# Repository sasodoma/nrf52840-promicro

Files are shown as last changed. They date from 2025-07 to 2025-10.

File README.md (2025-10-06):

# nRF52840 ProMicro

The nRF52840 ProMicro board is also known as the SuperMini board. It's a clone of the nice!nano board with a mix of v1 and v2 design features. The schematic is available online, albeit with a small mistake, but I was unable to find board design files. The aim of this repository is to reverse engineer the board design and determine which component is which so that I can desolder them from the board and reuse them on my custom PCB.

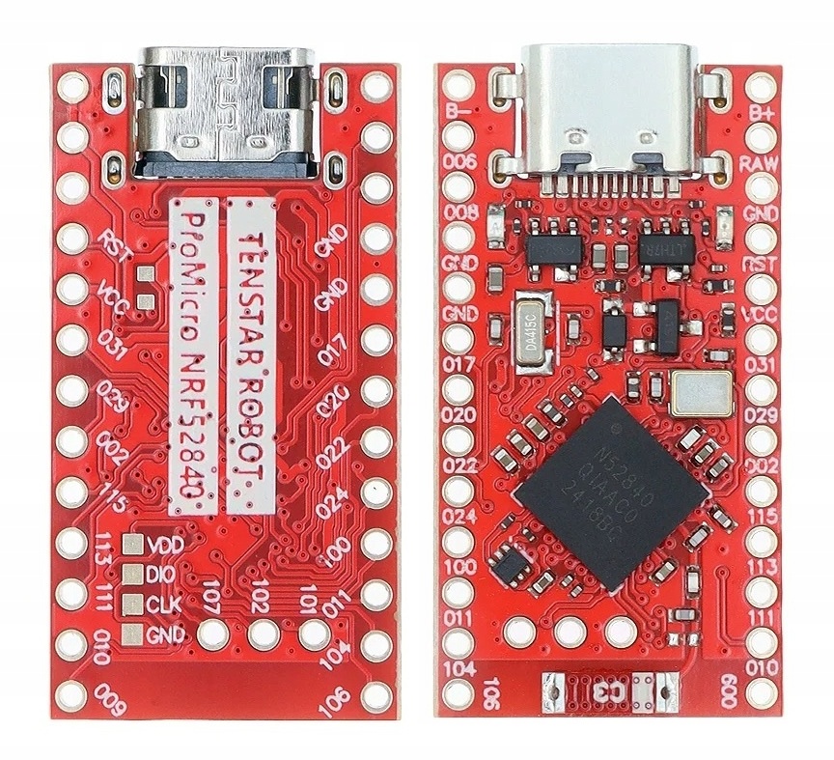
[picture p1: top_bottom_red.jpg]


# Schematic
This is the original schematic as posted on https://chat.nologo.tech/d/80. The voltage divider for the battery is marked as being connected to P0.04, which is an analog input pin. On the actual board it's connected to P0.24 instead, which makes it unsuitable for battery voltage measurements. Instead you can measure the battery directly on VDDH pin, but the voltage will rise when USB is plugged in. To prevent this incorrect reading, you can remove the NPQ2, NBD1 and NPR7 components, and instead bridge pins 3 and 2 on the NPQ2 MOSFET. This way the nRF chip will always draw power from the battery and USB will only charge the battery and thus power the board indirectly. The voltage on VDDH will then be the actual voltage of the battery (slightly higher while charging but it won't jump to 100%). This could be problematic if your board consumed more current than the charger provided, and the battery would discharge while plugged in, so keep that in mind.

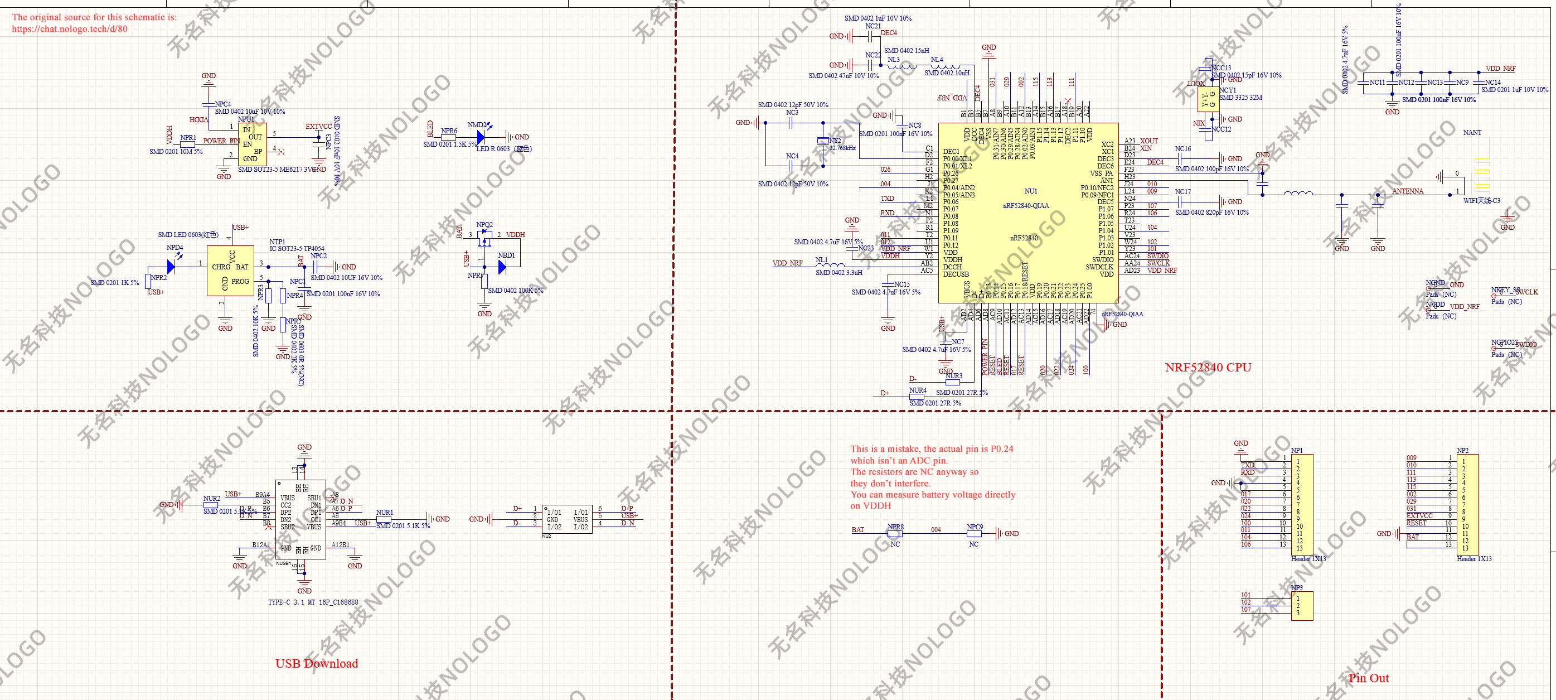
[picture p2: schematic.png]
Schematic of the nRF52840 ProMicro board


# Sleep current problems
I wanted to use these boards to create some low power BTHome sensors. I have boards from many different sources. Some exhibit great power consumption, only 4 uA in sleep, with EXTVCC disabled. Others had a consumption of 60 uA, which is still pretty good but it's 15x more. After some component swapping, I found the problem to be the W5 marked diode. This is supposed to be a BAT60B Schottky diode, with a voltage drop of 0.24 V. On the high power consumption boards I instead measured a drop of 0.7 V, indicating a regular silicon diode. What's more concerning is that apparently the reverse leakage current of this diode was also much worse and this is what was causing the power consumption.

# KiCad project
The project in the KiCad folder is my attempt at replicating the board to identify every component's location. The USB connector is not the correct footprint, but the name in the schematic is correct. KiCad doesn't seem to have a footprint for the antenna, but the model is CA-C03.

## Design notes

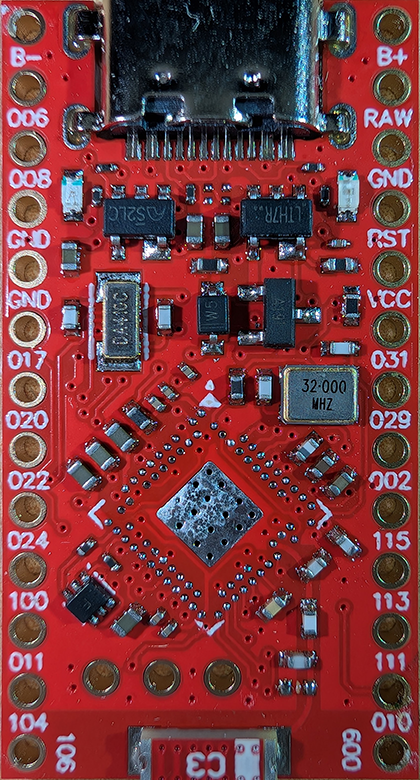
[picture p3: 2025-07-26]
KiCad/reference_top.png

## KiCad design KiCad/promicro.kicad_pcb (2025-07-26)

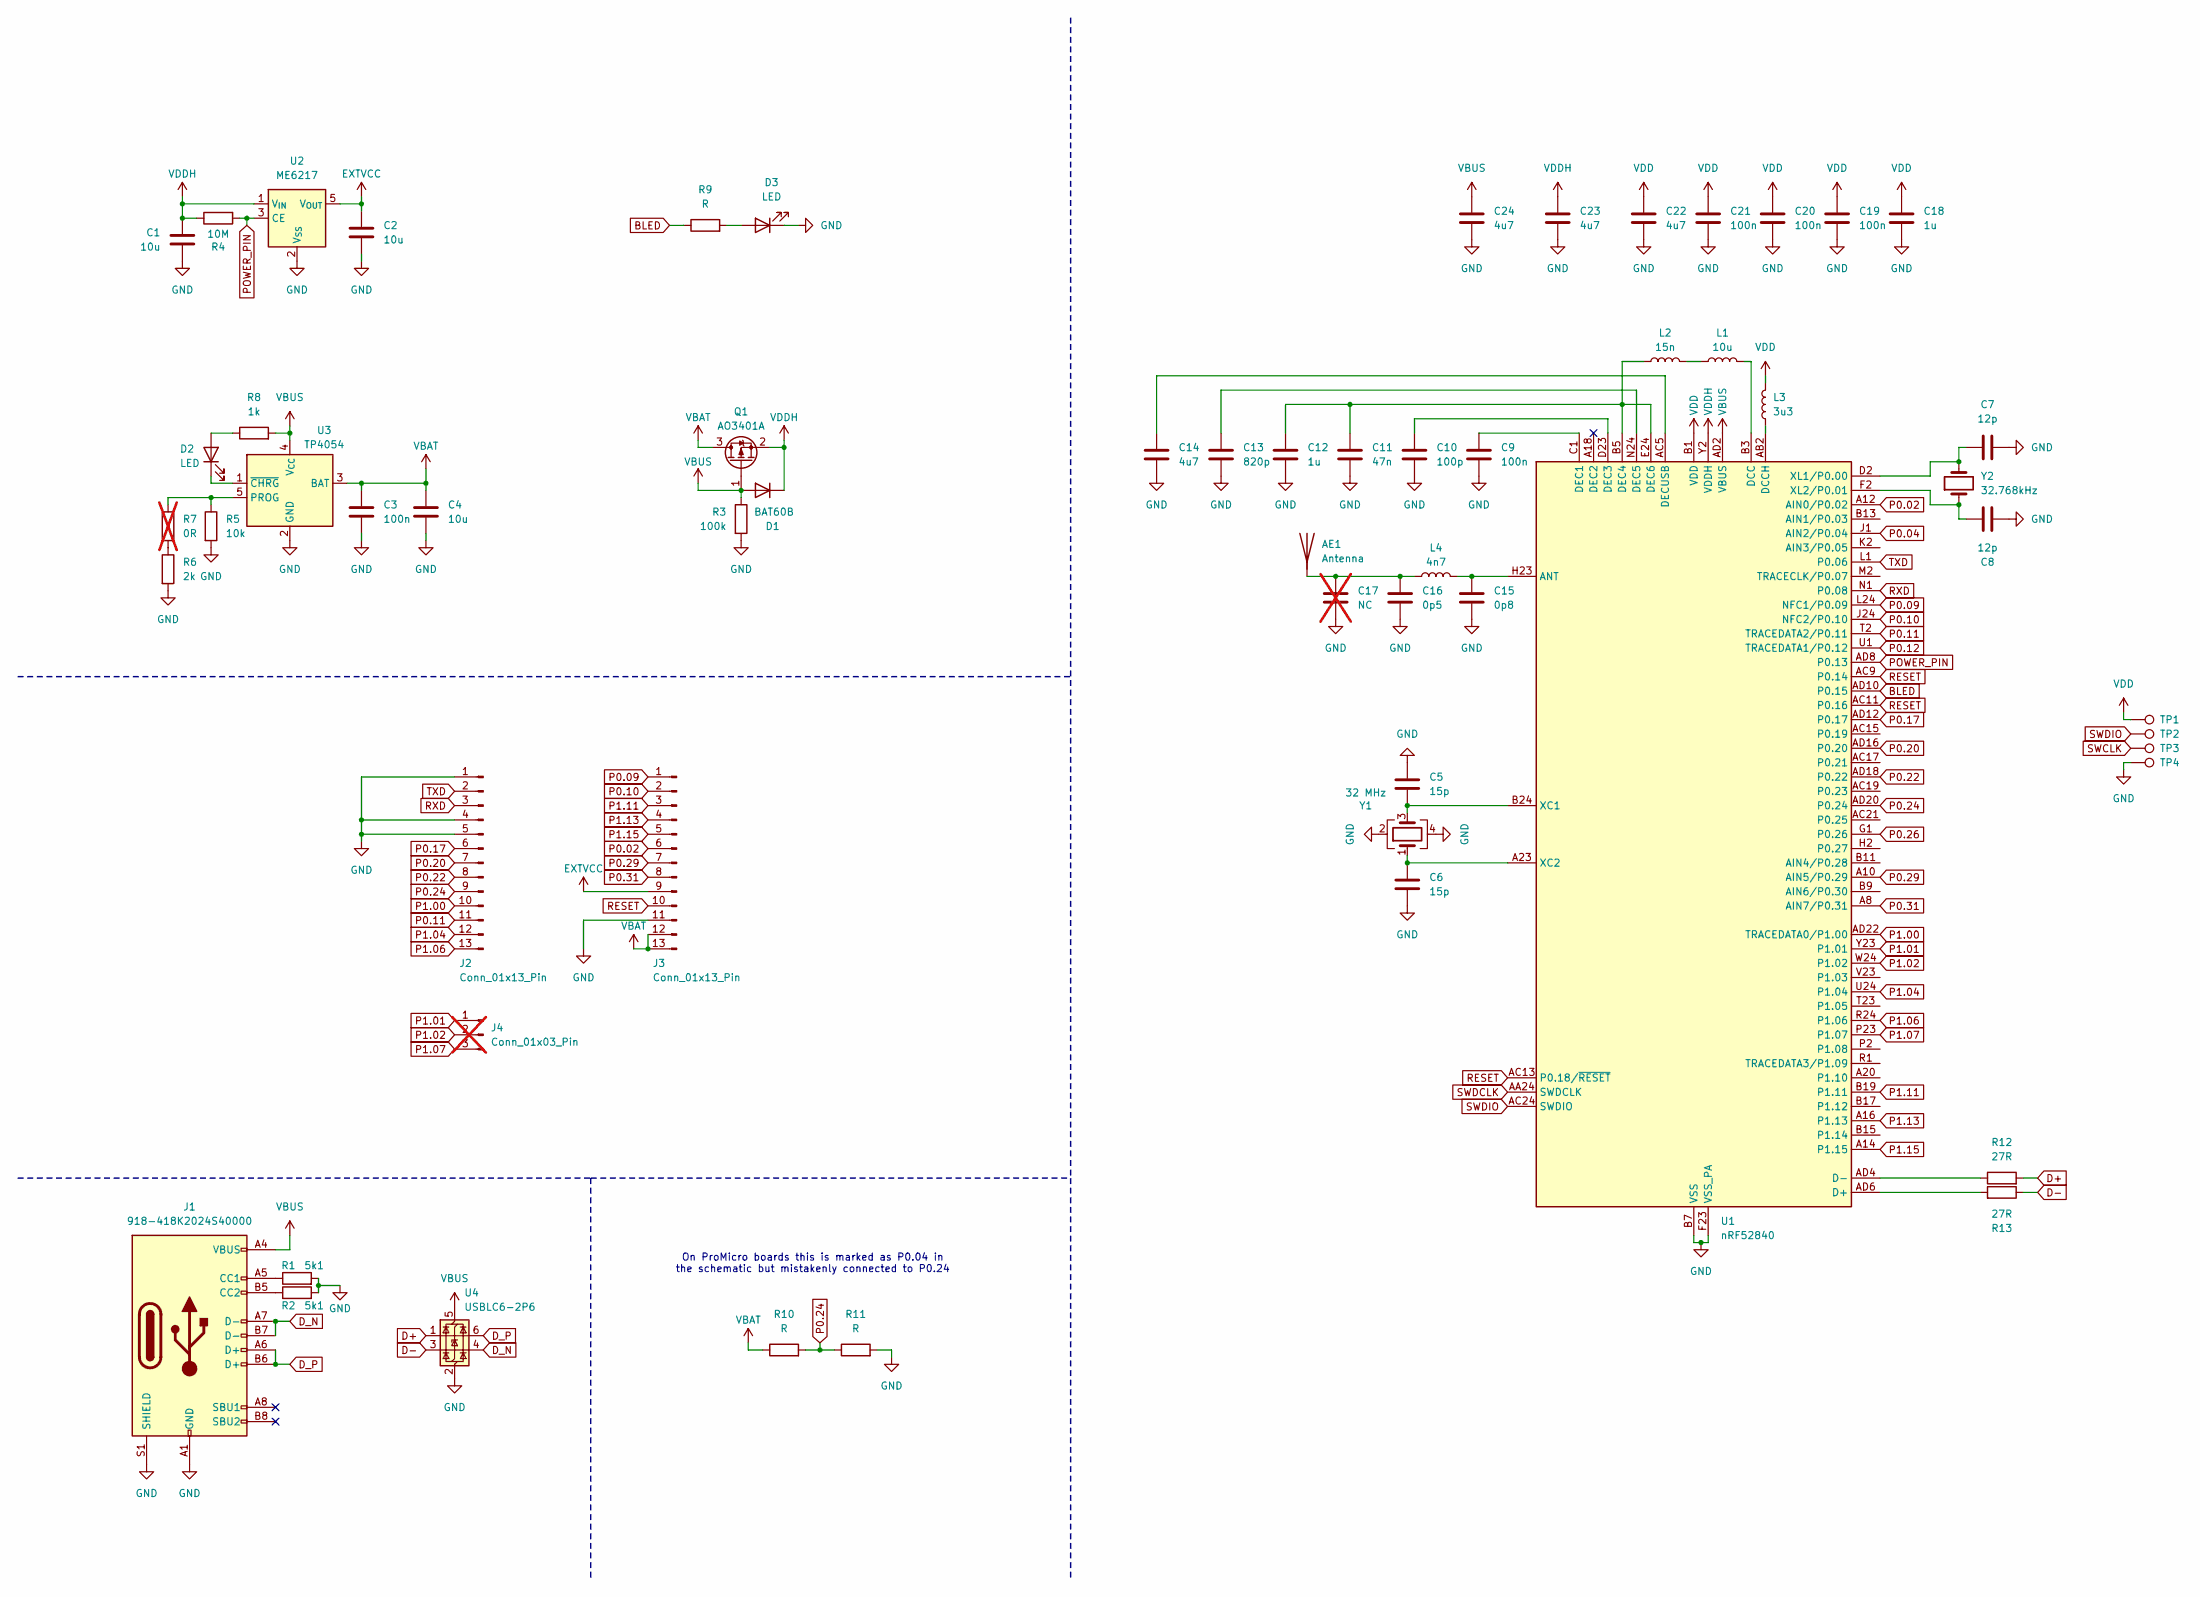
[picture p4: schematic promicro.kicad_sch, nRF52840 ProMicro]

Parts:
AE1: Antenna
C1, C2, C4: 10u; C_0402_1005Metric
C3, C9, C19, C20, C21: 100n; C_0201_0603Metric
C5, C6: 15p; C_0402_1005Metric
C7, C8: 12p; C_0402_1005Metric
C10: 100p; C_0402_1005Metric
C11: 47n; C_0402_1005Metric
C12: 1u; C_0402_1005Metric
C13: 820p; C_0402_1005Metric
C14, C22, C23, C24: 4u7; C_0402_1005Metric
C15: 0p8; C_0402_1005Metric
C16: 0p5; C_0402_1005Metric
C17: NC; C_0402_1005Metric; not fitted
C18: 1u; C_0201_0603Metric
D1: BAT60B; D_SOD-323
D2, D3: LED; LED_0603_1608Metric
J1: 918-418K2024S40000; USB_C_Receptacle_GCT_USB4105-xx-A_16P_TopMnt_Horizontal
J2, J3: Conn_01x13_Pin; PinHeader_1x13_P2.54mm_Vertical
J4: Conn_01x03_Pin; PinHeader_1x03_P2.54mm_Vertical; not fitted
L1: 10u; L_0402_1005Metric
L2: 15n; L_0402_1005Metric
L3: 3u3; L_0402_1005Metric
L4: 4n7; L_0402_1005Metric
Q1: AO3401A; SOT-23
R1, R2: 5k1; R_0201_0603Metric
R3: 100k; R_0402_1005Metric
R4: 10M; R_0201_0603Metric
R5: 10k; R_0402_1005Metric
R6: 2k; R_0402_1005Metric
R7: 0R; R_0603_1608Metric; not fitted
R8: 1k; R_0201_0603Metric
R9, R10, R11: R; R_0201_0603Metric
R12, R13: 27R; R_0201_0603Metric
TP1, TP2, TP3, TP4: TestPoint; TestPoint_Pad_1.0x1.0mm
U1: nRF52840; Nordic_AQFN-73-1EP_7x7mm_P0.5mm
U2: ME6217; SOT-23-5
U3: TP4054; TSOT-23-5
U4: USBLC6-2P6; SOT-666
Y1: 32 MHz; Crystal_SMD_3225-4Pin_3.2x2.5mm
Y2: 32.768kHz; Crystal_SMD_G8-2Pin_3.2x1.5mm

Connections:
BLED: R9.1, U1.AD10 (P0.15)
D+: R12.2, U4.1 (I/O1)
D-: R13.1, U4.3 (I/O2)
D_N: J1.A7 (D-), J1.B7 (D-), U4.4 (I/O2)
D_P: J1.A6 (D+), J1.B6 (D+), U4.6 (I/O1)
EXTVCC: C2.1, J3.9, U2.5 (V_{OUT})
GND: C1.2, C2.2, C3.2, C4.2, C5.1, C6.2, C7.2, C8.2, C9.2, C10.2, C11.2, C12.2, C13.2, C14.2, C15.2, C16.2, C17.2, C18.2, C19.2, C20.2, C21.2, C22.2, C23.2, C24.2, D3.1 (K), J1.A1 (GND), J1.A12 (GND), J1.B1 (GND), J1.B12 (GND), J1.S1 (SHIELD), J2.1, J2.4, J2.5, J3.11, R1.2, R2.2, R3.2, R5.2, R6.2, R11.2, TP4.1, U1.B7 (VSS), U1.EP (VSS), U1.F23 (VSS_PA), U2.2 (V_{SS}), U3.2 (GND), U4.2 (GND), Y1.2, Y1.4
unnamed: AE1.1, C16.1, C17.1, L4.1
unnamed: D2.2 (A), R8.1
unnamed: D2.1 (K), U3.1 (~CHRG)
unnamed: D3.2 (A), R9.2
unnamed: J1.A5 (CC1), R1.1
unnamed: J1.B5 (CC2), R2.1
unnamed: L1.1, L2.2
unnamed: R6.1, R7.2
unnamed: C15.1, L4.2, U1.H23 (ANT)
unnamed: R13.2, U1.AD6 (D+)
unnamed: R12.1, U1.AD4 (D-)
unnamed: L1.2, U1.B3 (DCC)
unnamed: L3.1, U1.AB2 (DCCH)
unnamed: C9.1, U1.C1 (DEC1)
unnamed: C10.1, U1.D23 (DEC3)
unnamed: C11.1, C12.1, L2.1, U1.B5 (DEC4), U1.E24 (DEC6)
unnamed: C13.1, U1.N24 (DEC5)
unnamed: C14.1, U1.AC5 (DECUSB)
unnamed: C5.2, U1.B24 (XC1), Y1.3
unnamed: C6.1, U1.A23 (XC2), Y1.1
unnamed: C7.1, U1.D2 (XL1/P0.00), Y2.2
unnamed: C8.1, U1.F2 (XL2/P0.01), Y2.1
unnamed: R5.1, R7.1, U3.5 (PROG)
P0.02: J3.6, U1.A12 (AIN0/P0.02)
P0.04: U1.J1 (AIN2/P0.04)
P0.09: J3.1, U1.L24 (NFC1/P0.09)
P0.10: J3.2, U1.J24 (NFC2/P0.10)
P0.11: J2.11, U1.T2 (TRACEDATA2/P0.11)
P0.12: U1.U1 (TRACEDATA1/P0.12)
P0.17: J2.6, U1.AD12 (P0.17)
P0.20: J2.7, U1.AD16 (P0.20)
P0.22: J2.8, U1.AD18 (P0.22)
P0.24: J2.9, R10.2, R11.1, U1.AD20 (P0.24)
P0.26: U1.G1 (P0.26)
P0.29: J3.7, U1.A10 (AIN5/P0.29)
P0.31: J3.8, U1.A8 (AIN7/P0.31)
P1.00: J2.10, U1.AD22 (TRACEDATA0/P1.00)
P1.01: J4.1, U1.Y23 (P1.01)
P1.02: J4.2, U1.W24 (P1.02)
P1.04: J2.12, U1.U24 (P1.04)
P1.06: J2.13, U1.R24 (P1.06)
P1.07: J4.3, U1.P23 (P1.07)
P1.11: J3.3, U1.B19 (P1.11)
P1.13: J3.4, U1.A16 (P1.13)
P1.15: J3.5, U1.A14 (P1.15)
POWER_PIN: R4.2, U1.AD8 (P0.13), U2.3 (CE)
RESET: J3.10, U1.AC9 (P0.14), U1.AC11 (P0.16), U1.AC13 (P0.18/~RESET)
RXD: J2.3, U1.N1 (P0.08)
SWCLK: TP3.1
SWDCLK: U1.AA24 (SWDCLK)
SWDIO: TP2.1, U1.AC24 (SWDIO)
TXD: J2.2, U1.L1 (P0.06)
VBAT: C3.1, C4.1, J3.12, J3.13, Q1.3 (D), R10.1, U3.3 (BAT)
VBUS: C24.1, D1.2 (A), J1.A4 (VBUS), J1.A9 (VBUS), J1.B4 (VBUS), J1.B9 (VBUS), Q1.1 (G), R3.1, R8.2, U1.AD2 (VBUS), U3.4 (V_{CC}), U4.5 (VBUS)
VDD: C18.1, C19.1, C20.1, C21.1, C22.1, L3.2, TP1.1, U1.A22 (VDD), U1.AD14 (VDD), U1.AD23 (VDD), U1.B1 (VDD), U1.W1 (VDD)
VDDH: C1.1, C23.1, D1.1 (K), Q1.2 (S), R4.1, U1.Y2 (VDDH), U2.1 (V_{IN})

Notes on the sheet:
On ProMicro boards this is marked as P0.04 in the schematic but mistakenly connected to P0.24

Board: 2 copper layers, 59 parts (7 on the bottom side), 58 nets, no tracks yet.

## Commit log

2025-07-26 Add schematic
2025-07-26 Add KiCad project
    [promicro.kicad_pcb, promicro.kicad_sch]
2025-10-03 Document sleep current problems and diode findings
    Added section on sleep current problems and diode issues.
2025-10-06 Update README with battery measurement instructions
    Expanded explanation of the schematic and battery voltage measurement adjustments.
2025-10-23 Fix USB pins
    [promicro.kicad_sch]
